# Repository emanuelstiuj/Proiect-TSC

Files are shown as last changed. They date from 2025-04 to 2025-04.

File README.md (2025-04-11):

# OpenBook - E-Reader Project  
**Developed by Emanuel-Stefan Stiuj - TSC 2025**

The OpenBook is an innovative, open-source e-reader designed for low power consumption, expandability, and ease of use. Built around the ESP32-C6-WROOM-1-N8 microcontroller, this project integrates an e-paper display, environmental sensing, real-time clock functionality, and robust storage options into a portable, battery-powered device. This README provides a detailed breakdown of the hardware design, functionality, and implementation, ensuring all critical aspects are covered.

---

board

## Project Overview

OpenBook is a fully functional e-reader that leverages modern hardware to deliver a seamless reading experience. Key features include:
- A 7.5-inch e-paper display for crisp, low-power text rendering.
- Wi-Fi 6 and Bluetooth 5 connectivity via the ESP32-C6 for wireless content updates.
- SD card and external flash storage for e-books and logs.
- Environmental monitoring with the BME688 sensor (temperature, humidity, pressure, air quality).
- Precise timekeeping with the DS3231 RTC module.
- USB-C for power, charging, and data transfer, with a Li-Po battery for portability.
- Expandability through a Qwiic I²C connector.

The design prioritizes energy efficiency, modularity, and user interaction via three tactile buttons, making it ideal for avid readers and hardware enthusiasts alike.

---

## Hardware Architecture

The OpenBook hardware architecture integrates several key components powered through a USB-C input and a Li-Po battery. The system uses a battery charger (MCP73831) to manage the 2500mAh Li-Po battery, which supplies power to an LDO regulator outputting 3.3V. This voltage powers the ESP32-C6-WROOM-1-N8 microcontroller, a 7.5-inch e-paper display, an SD card module, a 64MB NOR Flash, a DS3231 RTC, a BME688 sensor, and a MAX17048 fuel gauge. The ESP32 connects to the display, SD card, and flash via SPI, to the RTC, sensor, and fuel gauge via I²C, and to three tactile buttons via GPIO. The USB-C also provides data connectivity, and a Qwiic connector enables I²C expansion.

---

## Hardware Components and Functionality

### 1. Main Microcontroller: ESP32-C6-WROOM-1-N8
- **Processor**: 32-bit RISC-V, up to 160 MHz.
- **Memory**: 512 KB SRAM + 64 MB external NOR Flash (W25Q512JVEIQ).
- **Connectivity**: Wi-Fi 6 (2.4 GHz), Bluetooth 5 LE, USB 2.0.
- **Interfaces**: SPI, I²C, UART, GPIO.
- **Power**: 3.3V via LDO; supports deep sleep for minimal power use (<10 µA).
- **Why Chosen?**: Offers robust wireless capabilities, ample GPIO, and low-power modes, perfect for an e-reader with connectivity needs.

### 2. E-Paper Display
- **Type**: 7.5-inch Waveshare e-ink display (800x480 resolution).
- **Interface**: 4-wire SPI (MOSI, SCK, CS, DC) + control signals (RST, BUSY).
- **Pins**:
  - `EPD_CS` → `IO10`
  - `EPD_DC` → `IO5`
  - `EPD_RST` → `IO23`
  - `EPD_BUSY` → `IO3`
  - Shared SPI: `MOSI` (`IO7`), `SCK` (`IO6`).
- **Power**: 3.3V, ~20-50 mA during refresh, near-zero in static mode.
- **Why Chosen?**: E-paper’s ultra-low static power consumption makes it ideal for prolonged reading without draining the battery.

### 3. Storage
- **SD Card Module**:
  - **Interface**: SPI.
  - **Pins**: `SS_SD` → `IO4`, `MOSI` → `IO7`, `MISO` → `IO2`, `SCK` → `IO6`.
  - **Purpose**: External storage for e-books and firmware updates.
- **External Flash (W25Q512JVEIQ)**:
  - **Interface**: SPI (Quad I/O).
  - **Pins**: `FLASH_CS` → `IO11`, shared `MOSI`, `MISO`, `SCK`.
  - **Capacity**: 64 MB for firmware and content.
- **Power**: Both operate at 3.3V, with ~10-100 mA during active use.

### 4. Real-Time Clock (RTC): DS3231SN
- **Interface**: I²C.
- **Pins**: `SDA` → `IO21`, `SCL` → `IO22`, `INT_RTC` → `IO8`, `32KHZ` → `IO1`, `RTC_RST` → `IO18`.
- **Power**: 3.3V, <1 µA with backup (super-capacitor or coin cell).
- **Why Chosen?**: Provides accurate timekeeping, critical for timestamped logs or scheduled tasks, even when powered off.

### 5. Environmental Sensor: BME688
- **Measurements**: Temperature, humidity, pressure, VOC/eCO2.
- **Interface**: I²C (shared bus with RTC and Fuel Gauge).
- **Pins**: `SDA` → `IO21`, `SCL` → `IO22`.
- **Power**: 3.3V, ~0.8-3.6 mA active, <1 µA in sleep.
- **Why Chosen?**: Enhances user experience by monitoring reading conditions.

### 6. Power Management
- **Battery**: 2500 mAh Li-Po (3.7V nominal).
- **Charger**: MCP73831, charges via USB-C at up to 1A.
- **Fuel Gauge**: MAX17048, I²C (`SDA`/`SCL`), monitors battery level (~50 µA).
- **LDO Regulator**: XC6220A331MR-G, steps 5V down to 3.3V for all components.
- **USB-C**: Power input (5V) and data (USB_D+ → `IO13`, USB_D- → `IO12`).
- **Protection**: Reverse polarity diodes, ESD protection (USBLC6-2SC6Y).

---

## Communication Interfaces

| Interface | Components | ESP32-C6 Pins | Notes |
|---|---|---|---|
| SPI | E-Paper, SD Card, Flash| `MOSI` (`IO7`), `MISO` (`IO2`), `SCK` (`IO6`) | Shared bus with individual CS pins. |
| I²C | RTC, BME688, Fuel Gauge| `SDA` (`IO21`), `SCL` (`IO22`) | 400 kHz bus, pull-ups included. |
| UART | Debugging | `TXD0`, `RXD0` (test pads) | Optional, for development.  |
| GPIO | Buttons, Status | `IO0`-`IO23` | Flexible assignments. |
| USB | Power/Data | `USB_D+` (`IO13`), `USB_D-` (`IO12`) | USB 2.0 full-speed. |

---

## Power Consumption

| Component | Typical Current (mA) | Notes |
|---|---|---|
| ESP32-C6 (Idle) | ~10 | <10 µA in deep sleep. |
| ESP32-C6 (Wi-Fi) | 80-160 | Peak during wireless activity. |
| E-Paper (Refresh) | 20-50 | Near-zero when static. |
| SD Card | 30-100 | Active during read/write. |
| Flash (NOR) | 10-20 | Intermittent use. |
| BME688 | ~0.8-3.6 | <1 µA in sleep. |
| DS3231 RTC | ~0.2-3.5 | <1 µA with backup. |
| MAX17048 | ~0.05 | Continuous monitoring. |
| **Total (Typical)** | **150-250 mA** | Varies with usage; ~50 µA in sleep. |

**Battery Life**: With a 2500 mAh battery, OpenBook can last weeks in typical use (mostly static display) or hours during heavy Wi-Fi and refresh activity.

---

| **Component Name** | **Component Type** | **Link** |
|---|---|---|
| MicroSD_112ATA | microSD | [Attend SnapEDA](https://www.snapeda.com/parts/112A-TAAR-R03/Attend/view-part/) |
| LED_ADAFRUIT0603 | LED | [Kingbright SnapEDA](https://www.snapeda.com/parts/KP-1608SURCK/Kingbright/view-part/?ref=search&t=LED%200603) |
| CAP_CPH3225 | C | [Seiko SnapEDA](https://www.snapeda.com/parts/CPH3225A/Seiko/view-part/) |
| VREG_XC6220A | Voltage Regulator | [Torex Mouser](https://ro.mouser.com/ProductDetail/Torex-Semiconductor/XC6220A331MR-G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) |
| FUEL_MAX17048 | Cell Fuel Gauge with ModelGauge | [Analog Devices SnapEDA](https://www.snapeda.com/parts/MAX17048G+T10/Analog%20Devices/view-part/) |
| ESP32C6_MODULE | ESP32 | [Espressif SnapEDA](https://www.snapeda.com/parts/ESP32-C6-WROOM-1-N8/Espressif%20Systems/view-part/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) |
| DIODE_MBR0530 | Diode Schottky | [Onsemi SnapEDA](https://www.snapeda.com/parts/MBR0530/Onsemi/view-part/) |
| BME680_SENSOR | Env Sensor | [Bosch SnapEDA](https://www.snapeda.com/parts/BME680/Bosch%20Sensortec/view-part/?ref=search&t=bme680) |
| INDUCTOR_744043 | L | [Wurth Mouser](https://eu.mouser.com/ProductDetail/Wurth-Elektronik/744043680?qs=PGXP4M47uW6VkZq%252BkzjrHA%3D%3D) |
| CONNECTOR_QWIIC | PRT-14417 QWIIC_CONNECTOR | [SparkFun SnapEDA](https://www.snapeda.com/parts/PRT-14417/SparkFun/view-part/) |
| VARSISTOR_ESP | Varsistor (B72520T0350K062) | [TDK Mouser](https://ro.mouser.com/ProductDetail/EPCOS-TDK/B72520T0350K062?qs=dEfas%2FXlABIszF52uu7vrg%3D%3D) |
| RES_RCL0402 | R | [YAGEO ComponentSearch](https://componentsearchengine.com/part-view/R0402%201%25%20100%20K%20(RC0402FR-07100KL)/YAGEO) |
| TVS_PGB1010603 | Ipp Tvs Diode Surface Mount 0603 | [Littelfuse SnapEDA](https://www.snapeda.com/parts/PGB1010603MR/Littelfuse/view-part/) |
| MOSFET_SI1308 | MOSFET Transistor | [Vishay SnapEDA](https://www.snapeda.com/parts/SI1308EDL-T1-GE3/Vishay/view-part/) |
| BUTTON_EVQP7 | Button | [SnapEDA Button](https://www.snapeda.com/search/?q=EVQP7L01P&search-type=parts) |
| USBLC6_TVS | Ipp Tvs Diode Surface Mount | [STMicro SnapEDA](https://www.snapeda.com/parts/USBLC6-2SC6Y/STMicroelectronics/view-part/?ref=dk&t=USBLC6-2SC6Y&con_ref=None) |
| FLASH_W25Q512 | FLASH - NOR Memory | [Winbond SnapEDA](https://www.snapeda.com/parts/W25Q512JVEIQ/Winbond%20Electronics/view-part/?ref=search&t=W25Q512JVEIQ) |
| CAP_ESP32C0402 | C | [YAGEO ComponentSearch](https://componentsearchengine.com/part-view/CC0402MRX5R5BB106/YAGEO) |
| RTC_DS3231 | I²C-Integrated RTC/TCXO/Crystal | [Analog Devices SnapEDA](https://www.snapeda.com/parts/DS3231SN%23/Analog%20Devices/view-part/?ref=search&t=DS3231SN%23) |
| VDET_BD5229 | Voltage Detector | [Rohm SnapEDA](https://www.snapeda.com/parts/BD5229G-TR/Rohm/view-part/?ref=search&t=BD5229G-TR) |
| SCHOTTKY_SD0805 | Diode Schottky | [AVX ComponentSearch](https://componentsearchengine.com/part-view/SD0805S020S1R0/Kyocera%20AVX) |
| MOSFET_DMG2305 | T DMG2305UX-7 | [Diodes ComponentSearch](https://componentsearchengine.com/part-view/DMG2305UX-7/Diodes%20Incorporated) |
| CHARGE_MCP73831 | Tiny Integrated Li-Ion/Li-Poly Charge Mgnt Controller | [Microchip ComponentSearch](https://componentsearchengine.com/part-view/MCP73831T-2ACI%2FOT/Microchip) |
| CONNECTOR_FH34SRJ | FH34SRJ-24S-0.5SH(99) | [Hirose ComponentSearch](https://componentsearchengine.com/part-view/FH34SRJ-24S-0.5SH(99)/Hirose) |
| USB4110_GF | USB4110-GF-A | [GCT SnapEDA](https://www.snapeda.com/parts/USB4110-GF-A./Global%20Connector%20Technology/view-part/) |
| CAP_RCLPOL | C pol | [GrabCAD Tantalum](https://grabcad.com/library/tantalum-smd-capacitor-type-b-3528-1) |
| JUMPER_SJ | Jumper-SolderPasteJumper3way | [GrabCAD Jumper](https://grabcad.com/library/solder-jumpers-1) |

---

## ESP32-C6 Pin Assignments

| Pin | Signal | Function | Reason for Assignment |
|---|---|---|---|
| EN | RESET | System reset | Standard reset pin for ESP32. |
| IO0 | INT_RTC | RTC interrupt | Low-power interrupt capability. |
| IO1 | 32KHZ | 32 kHz RTC clock output | Drives accurate timekeeping. |
| IO2 | MISO | SPI data input (SD/Flash/Display)| Shared SPI bus input. |
| IO3 | EPD_BUSY | E-Paper busy status | Monitors display readiness. |
| IO4 | SS_SD | SD Card chip select | Dedicated CS for SD card. |
| IO5 | EPD_DC | E-Paper data/command | Distinguishes data vs. commands. |
| IO6 | SCK | SPI clock | Shared SPI clock signal. |
| IO7 | MOSI | SPI data output | Shared SPI output for peripherals. |
| IO9 | IO/BOOT | Boot button | Triggers boot mode or power-on. |
| IO10 | EPD_CS | E-Paper chip select | Dedicated CS for display. |
| IO11 | FLASH_CS | Flash chip select | Dedicated CS for NOR Flash. |
| IO12 | USB_D- | USB differential data - | Fixed USB pin. |
| IO13 | USB_D+ | USB differential data + | Fixed USB pin. |
| IO15 | IO/CHANGE | Page change button | User input for navigation. |
| IO18 | RTC_RST | RTC reset | Hardware reset for RTC. |
| IO21 | SDA | I²C data line | Shared I²C bus for sensors/RTC. |
| IO22 | SCL | I²C clock line | Shared I²C clock signal. |
| IO23 | EPD_RST | E-Paper reset | Hardware reset for display. |
| TXD0 | TX | UART transmit (debug) | Test pad for debugging. |
| RXD0 | RX | UART receive (debug) | Test pad for debugging. |

---

## Design Decisions

1. **Power Routing**: Power traces were prioritized and routed manually to ensure stability, followed by autorouting for signal lines.
2. **USB-C Integration**: Modified to avoid DRC errors, supporting both power and data seamlessly.
3. **E-Paper Choice**: Selected for its low power and readability, with a dedicated 3.3V supply controlled via a MOSFET (`EPD_3v3_c`) for efficiency.
4. **Modularity**: Qwiic connector and test pads enhance expandability and debuggability.
5. **ESD Protection**: Added to SPI, USB, and power lines to ensure durability.

---

## Implementation Steps

1. **Schematic Design**: Created in Autodesk Fusion, integrating all components with clear pin mappings.
2. **PCB Layout**: 
   - Defined GND plane and power net classes.
   - Applied custom routing rules for signal integrity.
   - Adjusted enclosure dimensions to fit the PCB.
3. **3D Modeling**: Designed battery and display mounts based on datasheets.
4. **Testing**: Used test pads for UART debugging and verified functionality.

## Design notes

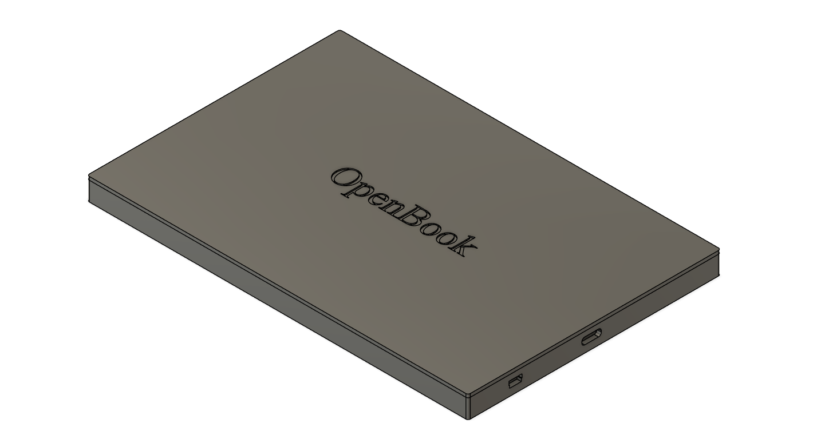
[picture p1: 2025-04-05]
Images/OpenBook_Enclosure.png

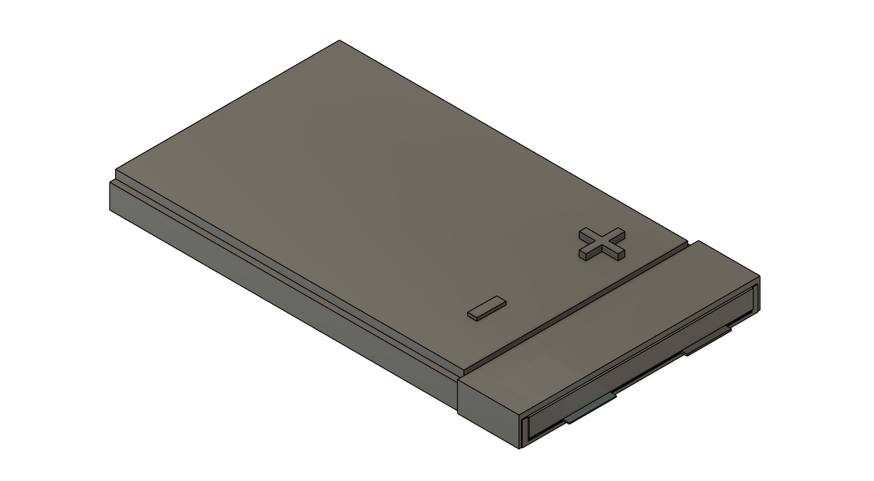
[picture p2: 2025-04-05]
Images/Battery.png

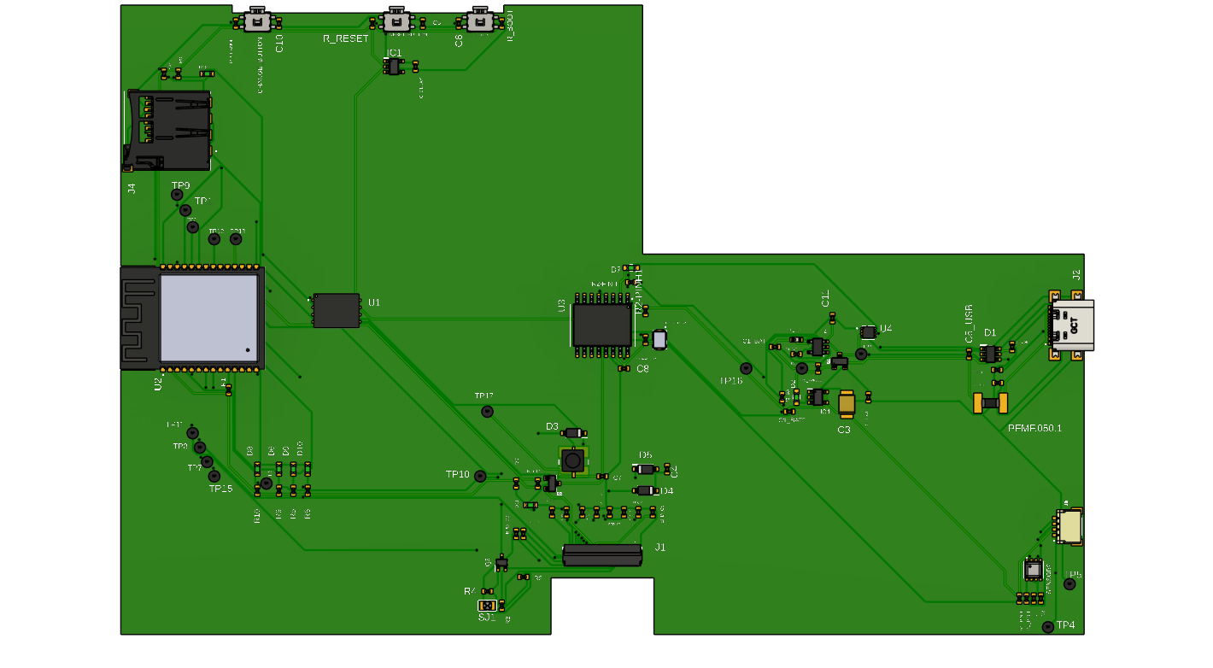
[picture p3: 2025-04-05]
Images/pcb_1.png

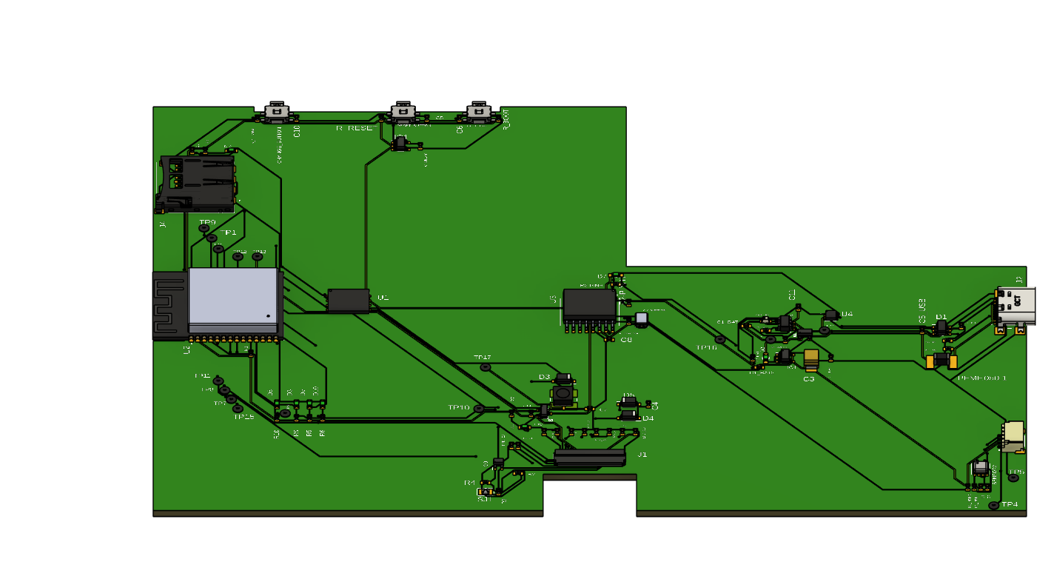
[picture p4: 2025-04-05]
Images/pcb_0.png

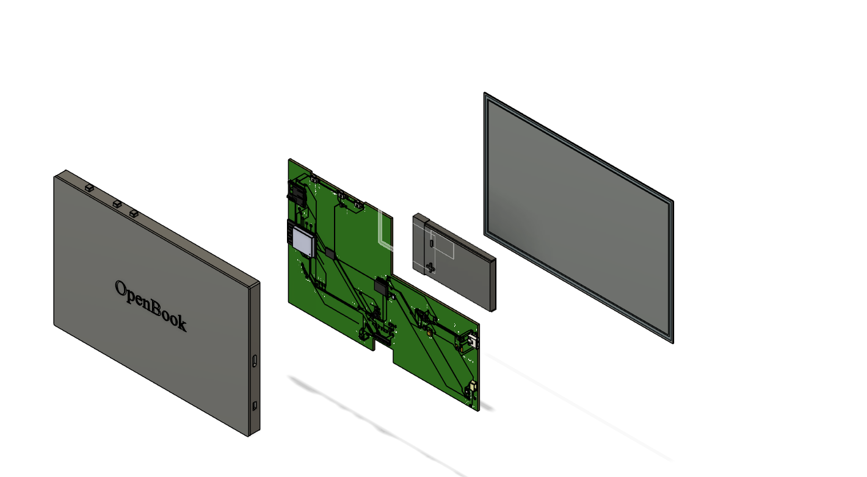
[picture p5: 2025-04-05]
Images/ExplodedView.png

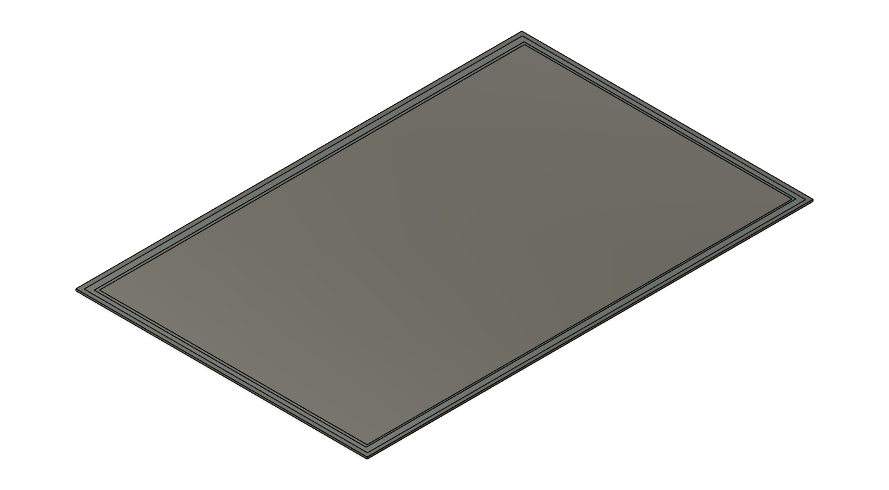
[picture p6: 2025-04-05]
Images/Display.png

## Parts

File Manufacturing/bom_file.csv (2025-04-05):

Qty | Value | Device | Package | Parts | Description | ARROW_PART_NUMBER | ARROW_PRICE-STOCK | AVAILABILITY | CENTROID_NOT_SPECIFIED | CHECK_PRICES | COPYRIGHT | DATASHEET | DESCRIPTION | DIGIKEY_DESCRIPTION | DIGIKEY_PART_NUMBER | HEIGHT | LEAD_FREE | MANUFACTURER_NAME | MANUFACTURER_PART_NUMBER | MF | MFR_NAME | MOUSER_PART_NUMBER | MOUSER_PRICE-STOCK | MOUSER_TESTING_PART_NUMBER | MOUSER_TESTING_PRICE-STOCK | MP | MPN | PACKAGE | POPULARITY | PREFIX | PRICE | PROD_ID | PURCHASE-URL | ROHS | SNAPEDA_LINK | SPICEPREFIX | TEMPERATURE_RANGE_HIGH | TEMPERATURE_RANGE_LOW | TP_SIGNAL_NAME | VALUE
1 |  | ADAFRUIT_LEDCHIP-LED0603 | ADAFRUIT_CHIP-LED0603 | CHG_LED | LED
1 |  | SJSJ_2WAY | SJ | SJ1 | SMD solder JUMPER
1 | 0.1uF/50V | ESP32_WROVER_EAGLE-LTSPICE_C | ESP32_WROVER_EAGLE-LTSPICE_C0402 | EPD_C5 | CAPACITOR, European symbol
1 | 0.47 | ESP32_WROVER_EAGLE-LTSPICE_R | ESP32_WROVER_EAGLE-LTSPICE_R0402 | R3 | RESISTOR, European symbol
1 | 100K | ESP32_WROVER_EAGLE-LTSPICE_R | ESP32_WROVER_EAGLE-LTSPICE_R0402 | R1_PWRUSB | RESISTOR, European symbol
8 | 100nF | ESP32_WROVER_EAGLE-LTSPICE_C | ESP32_WROVER_EAGLE-LTSPICE_C0402 | C1, C2, C4_USB, C6, C8, C9, C10, C_DELAY | CAPACITOR, European symbol
1 | 100uF TANT | RCL_CPOL-EUCT3528 | RCL_CT3528 | C3 | POLARIZED CAPACITOR, European symbol |  |  |  |  |  |  |  |  |  |  |  |  |  |  |  |  |  |  |  |  |  |  |  | 0 |  |  |  |  |  |  | C
16 | 10K | ESP32_WROVER_EAGLE-LTSPICE_R | ESP32_WROVER_EAGLE-LTSPICE_R0402 | R1, R1_PINH, R1_PINH1, R2-PINH, R2-PINH1, R4, R5, R6, R7, R8, R9, R10, R_BOOT, R_CHANGE, R_CL1, R_RESET | RESISTOR, European symbol
1 | 10uF | ESP32_WROVER_EAGLE-LTSPICE_C | ESP32_WROVER_EAGLE-LTSPICE_C0402 | C7 | CAPACITOR, European symbol
1 | 112A-TAAR-R03_ATTEND | 112A-TAAR-R03_ATTEND | 112ATAARR03ATTEND | J4 | Micro SD Card Socket, Push-Push Type, Top Mount, SMT, H=1.83mm, 10u |  |  |  |  |  |  |  | Micro SD Card Socket | Push-Push Type | Top Mount | SMT | H=1.83mm | 10u |  |  | 1.9mm |  | ATTEND | 112A-TAAR-R03 ATTEND
1 | 15 | ESP32_WROVER_EAGLE-LTSPICE_R | ESP32_WROVER_EAGLE-LTSPICE_R0402 | R_CAPACITOR | RESISTOR, European symbol
1 | 1uF | ESP32_WROVER_EAGLE-LTSPICE_C | ESP32_WROVER_EAGLE-LTSPICE_C0402 | C5 | CAPACITOR, European symbol
9 | 1uF/50V | ESP32_WROVER_EAGLE-LTSPICE_C | ESP32_WROVER_EAGLE-LTSPICE_C0402 | EPD_C1\, EPD_C2, EPD_C6, EPD_C7, EPD_C8, EPD_C9, EPD_C10, EPD_C11, EPD_C12 | CAPACITOR, European symbol
1 | 2.2 | ESP32_WROVER_EAGLE-LTSPICE_R | ESP32_WROVER_EAGLE-LTSPICE_R0402 | R2 | RESISTOR, European symbol
1 | 200 | ESP32_WROVER_EAGLE-LTSPICE_R | ESP32_WROVER_EAGLE-LTSPICE_R0402 | R1_BAT | RESISTOR, European symbol
2 | 20V/4.2A/52mO/1.4W | ESP32_WROVER_SPARKFUN-DISCRETESEMI_MOSFET_PCH-DMG2305UX-7 | ESP32_WROVER_SPARKFUN-DISCRETESEMI_SOT23-3 | Q1, Q2 | P-channel MOSFETs |  |  |  |  |  |  |  |  |  |  |  |  |  |  |  |  |  |  |  |  |  |  |  |  |  |  | TRAN-14388 |  |  |  |  |  |  |  | 20V/4.2A/52mO/1.4W
1 | 2K | ESP32_WROVER_EAGLE-LTSPICE_R | ESP32_WROVER_EAGLE-LTSPICE_R0402 | R2_BAT | RESISTOR, European symbol
5 | 4.7uF | ESP32_WROVER_EAGLE-LTSPICE_C | ESP32_WROVER_EAGLE-LTSPICE_C0402 | C1_BAT, C1_BAT1, C1_BAT2, C5_USB, C11 | CAPACITOR, European symbol
1 | 4.7uF/25V | ESP32_WROVER_EAGLE-LTSPICE_C | ESP32_WROVER_EAGLE-LTSPICE_C0402 | C4 | CAPACITOR, European symbol
2 | 5k1 | ESP32_WROVER_EAGLE-LTSPICE_R | ESP32_WROVER_EAGLE-LTSPICE_R0402 | R2-USB, R2-USB1 | RESISTOR, European symbol
1 | 68uH | 744043680IND_4828-WE-TPC_WRE | IND_4828-WE-TPC_WRE | L1 |  |  |  |  |  |  | Copyright (C) 2024 Ultra Librarian. All rights reserved. |  |  |  |  |  |  |  | 744043680 |  | Wurth Electronics
1 | BD5229G-TR | BD5229G-TR | SOT95P280X125-5N | IC1 | Voltage Detector with Adjustable Delay Time: CMOS processes are utilized to develop high precision, low current consumption CMOS reset ICs that allow arbitrary setting of the delay time. The extensive lineup includes both Nch Open Drain and CMOS output types in a wide range of detection voltages (from 2.3V to 6.0V, in 0.1V steps), enabling selection of the ideal solution based on customer requirements. In addition, the entire series is of course both lead-free and RoHS-compliant. |  |  |  |  |  |  |  | Voltage Detector with Adjustable Delay Time: CMOS processes are utilized to develop high precision | low current consumption CMOS reset ICs that allow arbitrary setting of the delay time. The extensive lineup includes both Nch Open Drain and CMOS output types in a wide range of detection voltages (from 2.3V to 6.0V | in 0.1V steps) | enabling selection of the ideal solution based on customer requirements. In addition | the entire series is of course both lead-free and RoHS-compliant. |  |  | 1.25mm |  | ROHM Semiconductor | BD5229G-TR |  |  | 755-BD5229G-TR | https://www.mouser.co.uk/ProductDetail/ROHM-Semiconductor/BD5229G-TR?qs=4kLU8WoGk0vvnhrrYwdszw%3D%3D
1 | BME688 | ESP32_WROVER_BME680_BME680 | ESP32_WROVER_BME680_PSON80P300X300X100-8N | SENSOR2 | Integrated Environmental Unit |  |  | Unavailable |  |  |  |  | Integrated Environmental Unit |  |  |  |  |  |  | Bosch Sensortec |  |  |  |  |  | BME680 |  | LGA-8 Bosch Tools |  |  | None
1 | BOOT_BUTTON | BUTTON_CUSYOMV1 | MYBUTTON | BOOT_BUTTON
1 | CHANGE_BUTTON | BUTTON_CUSYOMV1 | MYBUTTON | CHANGE_BUTTON
1 | CPH3225ACPH | CPH3225ACPH | CAPCP3225X100N | C10_SUPERCAP | Cap 0.011F 3.3V 1210 Flat Check availability
1 | DS3231SN# | DS3231SN# | SOIC127P1032X265-16N | U3 | Real Time Clock Serial 16-Pin SOIC W T/R Check availability |  |  | In Stock |  | https://www.snapeda.com/parts/DS3231SN%23/Analog+Devices/view-part/?ref=eda |  |  | Extremely Accurate I²C-Integrated RTC/TCXO/Crystal |  |  |  |  |  |  | Analog Devices |  |  |  |  |  | DS3231SN# |  | SOIC-16 Maxim |  |  | None |  | https://www.snapeda.com/api/url_track_click_mouser/?unipart_id=99048&manufacturer=Analog Devices&part_name=DS3231SN#&search_term=None |  | https://www.snapeda.com/parts/DS3231SN%23/Analog+Devices/view-part/?ref=snap
1 | ESP32-C6-WROOM-1-N8 | ESP32-C6-WROOM-1-N8 | XCVR_ESP32-C6-WROOM-1-N8 | U2 | Check availability |  |  | In Stock |  | https://www.snapeda.com/parts/ESP32-C6-WROOM-1-N8/Espressif+Systems/view-part/?ref=eda |  |  | Multiprotocol Modules ESP32-C6 module | Wi-Fi 6 in 2.4 GHz band | Bluetooth 5 | Zigbee 3.0 and Thread. ESP34-WROOM Compatible - ENGINEERING SAMPLE |  |  |  |  |  |  | Espressif Systems |  |  |  |  |  | ESP32-C6-WROOM-1-N8 |  | None |  |  | None |  |  |  | https://www.snapeda.com/parts/ESP32-C6-WROOM-1-N8/Espressif+Systems/view-part/?ref=snap
1 | ESP32C6_VARISTOR | ESP32C6_VARISTOR | ESP32C6_VARISTOR_CT/CN1812 | PFMF.050.1 | VARISTOR
1 | ESP32_WROVER_AVX---SD0805S020S1R0_AVX_SD0805S020S1R0_0_0AVX_SD0805S020S1R0_0_0 | ESP32_WROVER_AVX---SD0805S020S1R0_AVX_SD0805S020S1R0_0_0AVX_SD0805S020S1R0_0_0 | ESP32_WROVER_AVX---SD0805S020S1R0_AVX_SD0805S020S1R0_0 | D7 | Schottky Barrier Rectifier Diode |  |  |  | No |  |  | http://datasheets.avx.com/schottky.pdf |  | DIODE SCHOTTKY 20V 1A 0805 | 478-7800-1-ND |  | yes |  |  | AVX |  | 581-SD0805S020S1R0 |  |  |  |  |  | 0805 (2012 metric) |  | D |  |  |  | yes |  |  | +125°C | -55°C
1 | FH34SRJ-24S-0.5SH_99_FH34 | FH34SRJ-24S-0.5SH_99_FH34 | FH34SRJ24S05SH99 | J1 | (0.50mm) Surface Mount, Right Angle
1 | MAX17048G+T10 | MAX17048G+T10 | SON50P200X200X80-9N | U4 | Check availability |  |  | In Stock |  | https://www.snapeda.com/parts/MAX17048G+T10/Analog+Devices/view-part/?ref=eda |  |  | 3µA 1-Cell/2-Cell Fuel Gauge with ModelGauge |  |  |  |  |  |  | Analog Devices |  |  |  |  |  | MAX17048G+T10 |  | TDFN-8 Maxim |  |  | None |  | https://www.snapeda.com/api/url_track_click_mouser/?unipart_id=329239&manufacturer=Analog Devices&part_name=MAX17048G+T10&search_term=None |  | https://www.snapeda.com/parts/MAX17048G+T10/Analog+Devices/view-part/?ref=snap
3 | MBR0530 | MBR0530 | SOD3716X135N | D3, D4, D5 | ON SEMICONDUCTOR - MBR0530 - DIODE, SCHOTTKY, 0.5A, 30V, SOD-123 |  |  | In Stock |  | https://www.snapeda.com/parts/MBR0530/Onsemi/view-part/?ref=eda |  |  | Diode Schottky 30 V 500mA Surface Mount SOD-123 |  |  |  |  |  |  | ON Semiconductor |  |  |  |  |  | MBR0530 |  | SOD-123-2 ON Semiconductor |  |  | None |  | https://www.snapeda.com/api/url_track_click_mouser/?unipart_id=179458&manufacturer=ON Semiconductor&part_name=MBR0530&search_term=None |  | https://www.snapeda.com/parts/MBR0530/Onsemi/view-part/?ref=snap
1 | MCP73831 | ESP32_WROVER_SPARKFUN-IC-POWER_MCP73831 | ESP32_WROVER_SPARKFUN-IC-POWER_SOT23-5 | U5 | MCP73831T Li-Ion, Li-Pol Controller |  |  |  |  |  |  |  |  |  |  |  |  |  |  |  |  |  |  |  |  |  |  |  |  |  |  | IC-09995
6 | PGB1010603MR | PGB1010603MR | DIOC1608X36N | D6, D8, D9, D10, D11, D12 | Check availability |  |  | In Stock |  | https://www.snapeda.com/parts/PGB1010603MR/Littelfuse/view-part/?ref=eda |  |  | 150V (Typ) Clamp - Ipp Tvs Diode Surface Mount 0603 (1608 Metric) |  |  |  |  |  |  | Littelfuse Inc. |  |  |  |  |  | PGB1010603MR |  | 0603 Littelfuse Inc. |  |  | None |  | https://www.snapeda.com/api/url_track_click_mouser/?unipart_id=5659453&manufacturer=Littelfuse Inc.&part_name=PGB1010603MR&search_term=None |  | https://www.snapeda.com/parts/PGB1010603MR/Littelfuse/view-part/?ref=snap
1 | QWIIC_RIGHT_ANGLE | QWIIC_CONNECTORJS-1MM | JST04_1MM_RA | J3 | SparkFun I2C Standard Qwiic Connector |  |  |  |  |  |  |  |  |  |  |  |  |  |  |  |  |  |  |  |  |  |  |  |  |  |  | CONN-13694 |  |  |  |  |  |  |  | QWIIC_RIGHT_ANGLE
1 | RESET_BUTTON | BUTTON_CUSYOMV1 | MYBUTTON | RESET_BUTTON
1 | SAMACSYS_PARTS_USB4110-GF-A | SAMACSYS_PARTS_USB4110-GF-A | SAMACSYS_PARTS_USB4110GFA | J2 | CONN USB 2.0 TYPE-C R/A SMT |  |  |  |  |  |  |  | CONN USB 2.0 TYPE-C R/A SMT |  |  | 3.26mm |  | GCT (GLOBAL CONNECTOR TECHNOLOGY) | USB4110-GF-A |  |  | 640-USB4110-GF-A | https://www.mouser.co.uk/ProductDetail/GCT/USB4110-GF-A?qs=KUoIvG%2F9IlYiZvIXQjyJeA%3D%3D
1 | SD0805S020S1R0 | ESP32_WROVER_AVX---SD0805S020S1R0_AVX_SD0805S020S1R0_0_0AVX_SD0805S020S1R0_0_0 | ESP32_WROVER_AVX---SD0805S020S1R0_AVX_SD0805S020S1R0_0 | D2 | Schottky Barrier Rectifier Diode |  |  |  | No |  |  | http://datasheets.avx.com/schottky.pdf |  | DIODE SCHOTTKY 20V 1A 0805 | 478-7800-1-ND |  | yes |  |  | AVX |  | 581-SD0805S020S1R0 |  |  |  |  |  | 0805 (2012 metric) |  | D |  |  |  | yes |  |  | +125°C | -55°C
1 | SI1308EDL-T1-GE3 | SI1308EDL-T1-GE3 | SOT65P210X110-3N | Q3 | MOSFET N-Ch 30V 1.5A TrenchFET SC70 Vishay Si1308EDL-T1-GE3 N-channel MOSFET Transistor, 1.5 A, 30 V, 3-Pin SC-70 |  |  | In Stock |  | https://www.snapeda.com/parts/SI1308EDL-T1-GE3/Vishay+Siliconix/view-part/?ref=eda |  |  | Si1308EDL-T1-GE3 N-channel MOSFET Transistor | 1.5 A | 30 V | 3-Pin SC-70 | Siliconix / Vishay SI1308EDL-T1-GE3 |  |  |  |  |  |  | Vishay Siliconix |  |  |  |  |  | SI1308EDL-T1-GE3 |  | SOT-323 Vishay Semiconductor |  |  | None |  | https://www.snapeda.com/api/url_track_click_mouser/?unipart_id=274603&manufacturer=Vishay Siliconix&part_name=SI1308EDL-T1-GE3&search_term=None |  | https://www.snapeda.com/parts/SI1308EDL-T1-GE3/Vishay+Siliconix/view-part/?ref=snap
17 | TPTP20R | TPTP20R | TP20R | TP1, TP2, TP3, TP4, TP5, TP6, TP7, TP8, TP9, TP10, TP11, TP12, TP13, TP14, TP15, TP16, TP17 | Test pad |  |  |  |  |  |  |  |  |  |  |  |  |  |  |  |  |  |  |  |  |  |  |  | 2
1 | USBLC6-2SC6Y | USBLC6-2SC6Y | SOT95P280X145-6N | D1 | Low Cap. ESD Protection Auto SOT-23-6 STMicroelectronics USBLC6-2SC6Y, Dual Uni-Directional TVS Diode Array, 6-Pin SOT-23 |  |  | In Stock |  | https://www.snapeda.com/parts/USBLC6-2SC6Y/STMicroelectronics/view-part/?ref=eda |  |  | 17V Clamp 5A (8/20µs) Ipp Tvs Diode Surface Mount SOT-23-6 |  |  |  |  |  |  | STMicroelectronics |  |  |  |  |  | USBLC6-2SC6Y |  | SOT-23-6 STMicroelectronics |  |  | None |  |  |  | https://www.snapeda.com/parts/USBLC6-2SC6Y/STMicroelectronics/view-part/?ref=snap
1 | W25Q512JVEIQ | W25Q512JVEIQ | SON127P600X800X80-9N | U1 | Check availability |  |  | In Stock |  | https://www.snapeda.com/parts/W25Q512JVEIQ/Winbond+Electronics/view-part/?ref=eda |  |  | FLASH - NOR Memory IC 512Mb (64M x 8) SPI - Quad I/O 133 MHz 8-WSON (8x6) |  |  |  |  |  |  | Winbond Electronics |  |  |  |  |  | W25Q512JVEIQ |  | Package |  |  | None |  |  |  | https://www.snapeda.com/parts/W25Q512JVEIQ/Winbond+Electronics/view-part/?ref=snap
1 | XC6220A331MR-G | XC6220A331MR-G | SOT95P280X120-5N | IC4 | LDO Voltage Regulators |  |  |  |  |  |  |  | LDO Voltage Regulators |  |  | 1.2mm |  | Torex | XC6220A331MR-G |  |  | 865-XC6220A331MR-G | https://www.mouser.co.uk/ProductDetail/Torex-Semiconductor/XC6220A331MR-G?qs=AsjdqWjXhJ8ZSWznL1J0gg%3D%3D

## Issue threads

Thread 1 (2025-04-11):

Text size for component names on PCB is too small

teodora-voicu, 2025-04-11:
**Description:**
The reference designators (e.g., R1, C3) on the PCB are too small to read comfortably.

**Impact:**
Hard to identify components during assembly, testing, or debugging.

**Suggestion:**
Click right on the label -> _properties_

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

Increase the size

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

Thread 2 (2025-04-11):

Missing README file

teodora-voicu, 2025-04-11:
**Description**
The repository currently does not include a README.md file.

**Impact**
It’s hard to understand the purpose, setup steps, and usage of the project without any documentation.

**Suggestion**
Add a README.md file with at least the minimum required structure.
For reference, the expected contents are described here: [https://ocw.cs.pub.ro/courses/tsc/proiect2025](url)

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

Closed 2025-04-13.

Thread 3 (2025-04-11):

PCB thickness should be 1 mm instead of 1.6 mm

teodora-voicu, 2025-04-11:
**Description**
The PCB thickness is currently set to 1.6 mm, although the project requirements specify a thickness of 1.0 mm.

**Impact**
Using a thicker PCB could lead to fitting issues with the enclosure or violate mechanical tolerances in the final assembly.

**Suggestion**

_Rules_ -> _Preferences_ -> _Layer Stack_

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

Change thickness to 1.0 mm

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

Closed 2025-04-13.

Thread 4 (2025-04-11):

Inductor footprint is too small

teodora-voicu, 2025-04-11:
**Description**
The footprint defined for the inductor appears to be smaller than the actual dimensions required by the physical component.

**Impact**
This could lead to soldering issues, mechanical stress, or the component not fitting properly on the PCB during assembly.

**Suggestion**
Update the footprint to match the recommended land pattern from the component’s datasheet.

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

Closed 2025-04-13.

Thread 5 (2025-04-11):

Test pads should display actual signal names, not generic labels

teodora-voicu, 2025-04-11:
**Description**
Currently, test pads are labeled with generic identifiers such as TP1, TP2, etc. These should be clearly labeled on the silkscreen with the actual signal names they correspond to (e.g., MISO, MOSI, RX, GND) for easier identification and debugging.

**Impact**
Generic labels make debugging and testing more difficult, especially for those unfamiliar with the board. Clear signal names improve usability, facilitate servicing, and minimize the risk of probing mistakes.

**Suggestion**
Right-click on each test pad, go to Properties, and update the name to reflect the corresponding signal.

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

Closed 2025-04-13.

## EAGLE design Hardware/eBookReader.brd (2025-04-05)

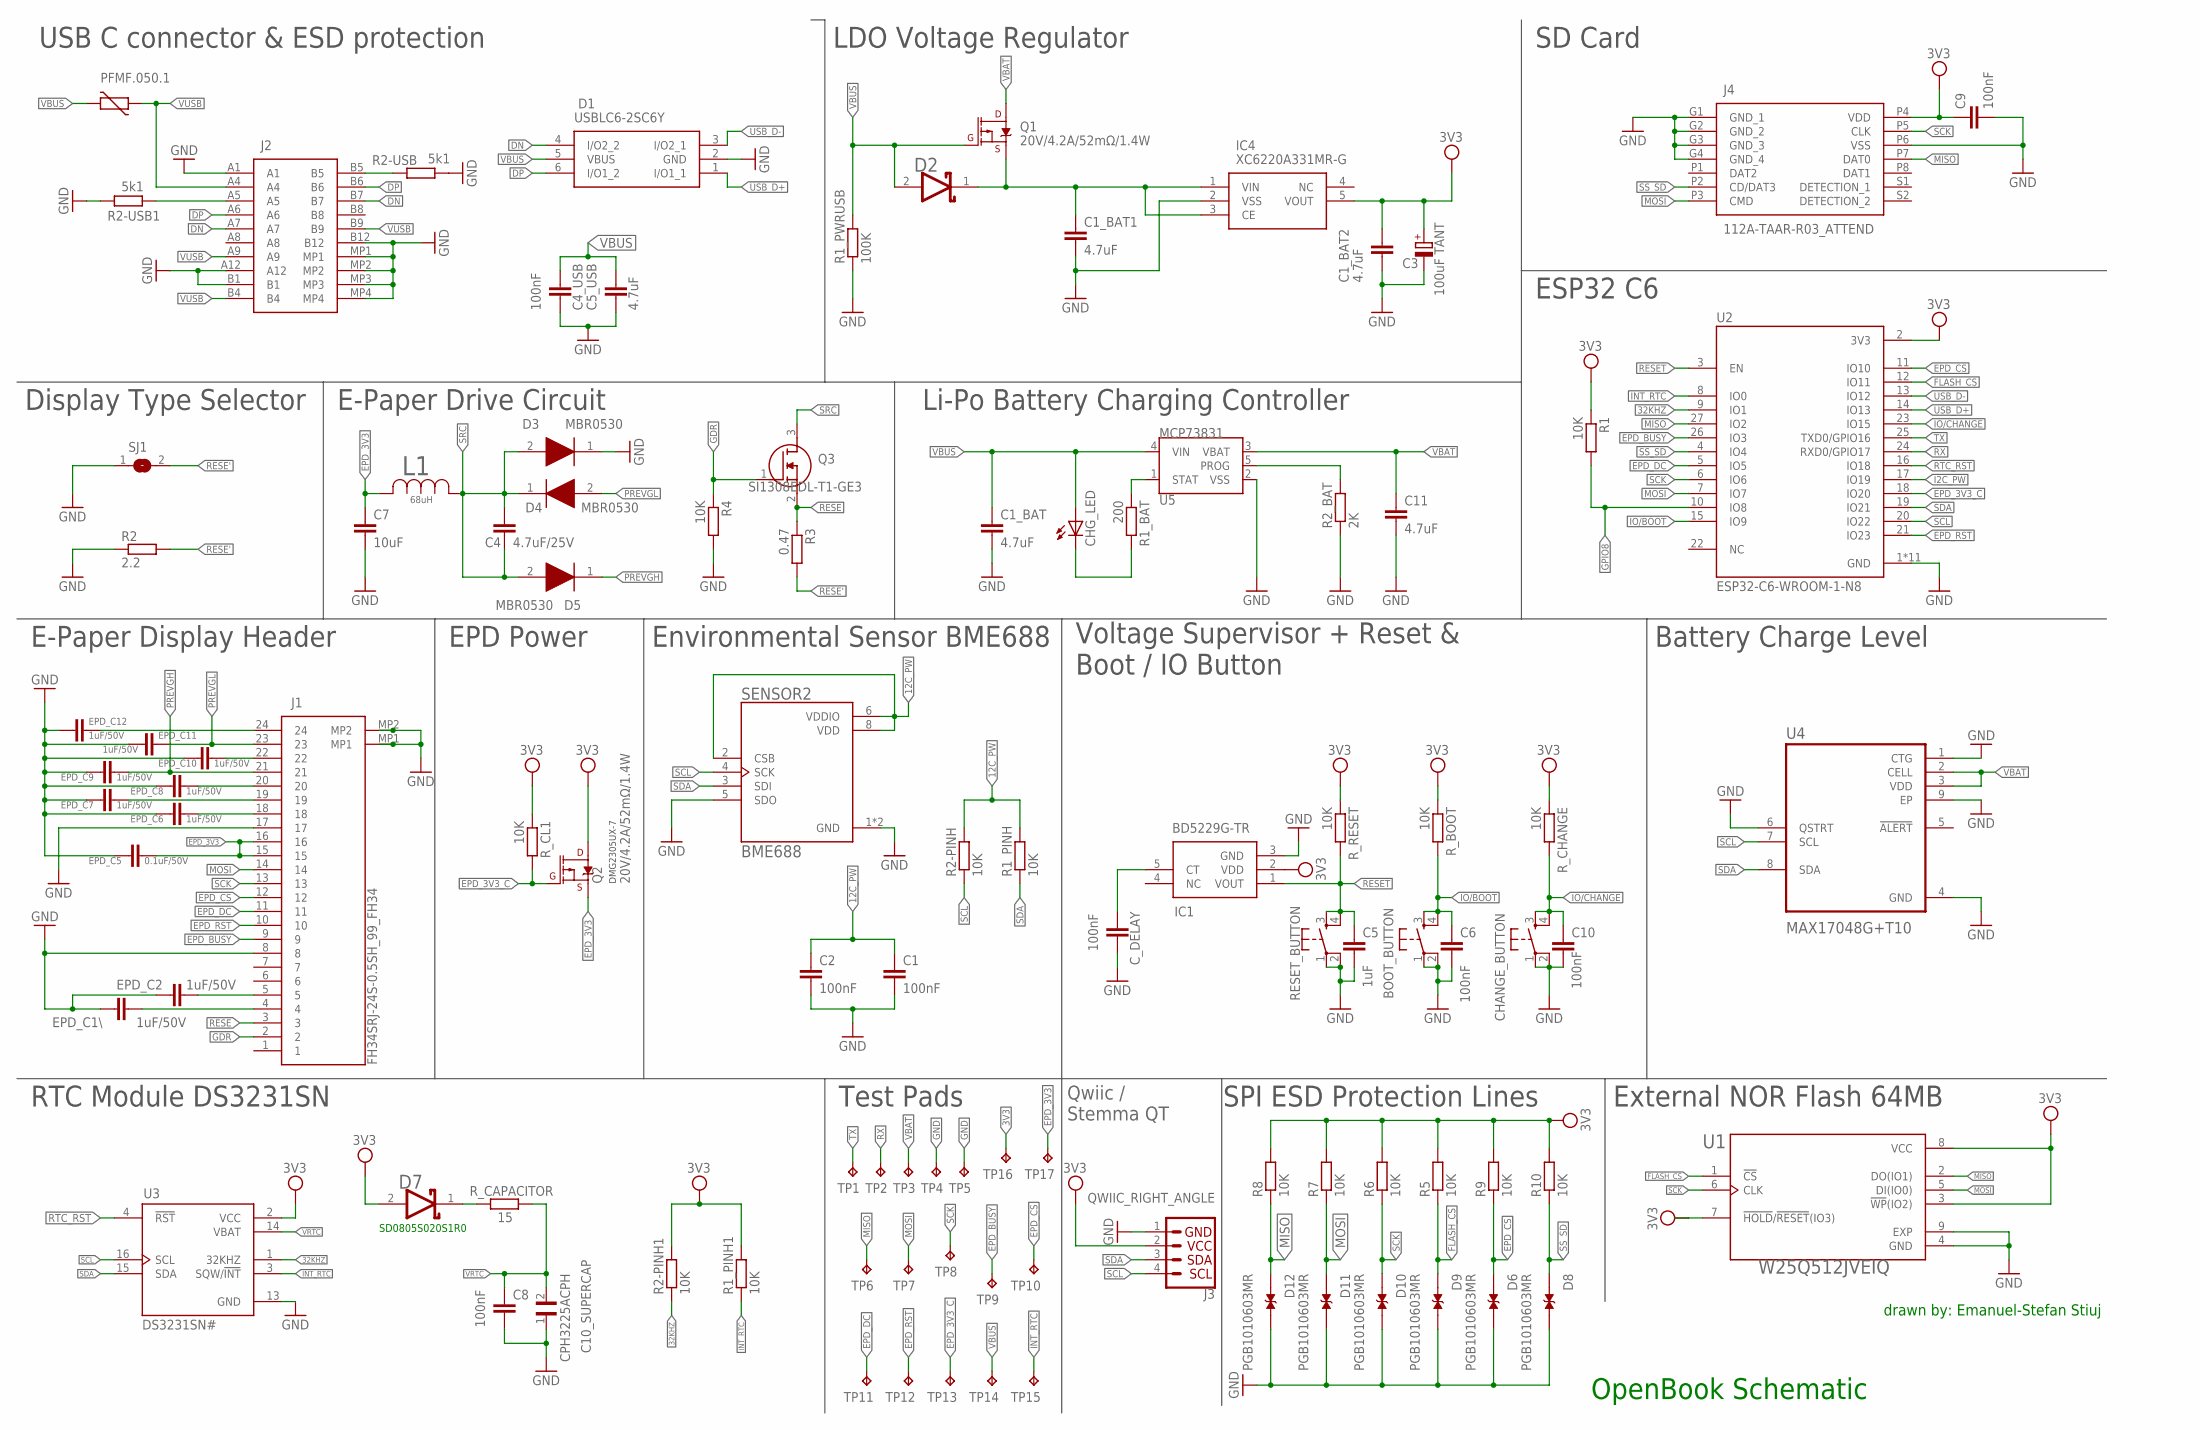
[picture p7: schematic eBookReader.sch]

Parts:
BOOT_BUTTON: BOOT_BUTTON; MYBUTTON
C1, C2, C4_USB, C6, C8, C9, C10: 100nF; ESP32_WROVER_EAGLE-LTSPICE_C0402
C1_BAT, C1_BAT1, C1_BAT2, C5_USB, C11: 4.7uF; ESP32_WROVER_EAGLE-LTSPICE_C0402
C3: 100uF TANT; RCL_CT3528
C4: 4.7uF/25V; ESP32_WROVER_EAGLE-LTSPICE_C0402
C5: 1uF; ESP32_WROVER_EAGLE-LTSPICE_C0402
C7: 10uF; ESP32_WROVER_EAGLE-LTSPICE_C0402
C10_SUPERCAP: CPH3225ACPH; CAPCP3225X100N
CHANGE_BUTTON: CHANGE_BUTTON; MYBUTTON
CHG_LED: ADAFRUIT_LEDCHIP-LED0603; ADAFRUIT_CHIP-LED0603
C_DELAY: 100nF; ESP32_WROVER_EAGLE-LTSPICE_C0402
D1: USBLC6-2SC6Y; SOT95P280X145-6N
D2: SD0805S020S1R0; ESP32_WROVER_AVX---SD0805S020S1R0_AVX_SD0805S020S1R0_0
D3, D4, D5: MBR0530; SOD3716X135N
D6, D8, D9, D10, D11, D12: PGB1010603MR; DIOC1608X36N
D7: ESP32_WROVER_AVX---SD0805S020S1R0_AVX_SD0805S020S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; ESP32_WROVER_AVX---SD0805S020S1R0_AVX_SD0805S020S1R0_0
EPD_C1\, EPD_C2, EPD_C6, EPD_C7, EPD_C8, EPD_C9, EPD_C10, EPD_C11, EPD_C12: 1uF/50V; ESP32_WROVER_EAGLE-LTSPICE_C0402
EPD_C5: 0.1uF/50V; ESP32_WROVER_EAGLE-LTSPICE_C0402
IC1: BD5229G-TR; SOT95P280X125-5N
IC4: XC6220A331MR-G; SOT95P280X120-5N
J1: FH34SRJ-24S-0.5SH_99_FH34; FH34SRJ24S05SH99
J2: SAMACSYS_PARTS_USB4110-GF-A; SAMACSYS_PARTS_USB4110GFA
J3: QWIIC_RIGHT_ANGLE; JST04_1MM_RA
J4: 112A-TAAR-R03_ATTEND; 112ATAARR03ATTEND
L1: 68uH; IND_4828-WE-TPC_WRE
PFMF.050.1: ESP32C6_VARISTOR; ESP32C6_VARISTOR_CT/CN1812
Q1, Q2: 20V/4.2A/52mΩ/1.4W; ESP32_WROVER_SPARKFUN-DISCRETESEMI_SOT23-3
Q3: SI1308EDL-T1-GE3; SOT65P210X110-3N
R1, R1_PINH, R1_PINH1, R2-PINH, R2-PINH1, R4, R5, R6, R7, R8, R9, R10: 10K; ESP32_WROVER_EAGLE-LTSPICE_R0402
R1_BAT: 200; ESP32_WROVER_EAGLE-LTSPICE_R0402
R1_PWRUSB: 100K; ESP32_WROVER_EAGLE-LTSPICE_R0402
R2: 2.2; ESP32_WROVER_EAGLE-LTSPICE_R0402
R2-USB, R2-USB1: 5k1; ESP32_WROVER_EAGLE-LTSPICE_R0402
R2_BAT: 2K; ESP32_WROVER_EAGLE-LTSPICE_R0402
R3: 0.47; ESP32_WROVER_EAGLE-LTSPICE_R0402
RESET_BUTTON: RESET_BUTTON; MYBUTTON
R_BOOT: 10K; ESP32_WROVER_EAGLE-LTSPICE_R0402
R_CAPACITOR: 15; ESP32_WROVER_EAGLE-LTSPICE_R0402
R_CHANGE: 10K; ESP32_WROVER_EAGLE-LTSPICE_R0402
R_CL1: 10K; ESP32_WROVER_EAGLE-LTSPICE_R0402
R_RESET: 10K; ESP32_WROVER_EAGLE-LTSPICE_R0402
SENSOR2: BME688; ESP32_WROVER_BME680_PSON80P300X300X100-8N
SJ1: SJSJ_2WAY; SJ
TP1, TP2, TP3, TP4, TP5, TP6, TP7, TP8, TP9, TP10, TP11, TP12, TP13, TP14, TP15, TP16, TP17: TPTP20R; TP20R
U1: W25Q512JVEIQ; SON127P600X800X80-9N
U2: ESP32-C6-WROOM-1-N8; XCVR_ESP32-C6-WROOM-1-N8
U3: DS3231SN#; SOIC127P1032X265-16N
U4: MAX17048G+T10; SON50P200X200X80-9N
U5: MCP73831; ESP32_WROVER_SPARKFUN-IC-POWER_SOT23-5

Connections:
3V3: C1_BAT2.1, C3.+, C9.1, D7.2 (ANODE), IC1.2 (VDD), IC4.4 (NC), IC4.5 (VOUT), J3.2, J4.P4 (VDD), Q2.3 (D), R1.1, R1_PINH1.2, R2-PINH1.2, R5.2, R6.2, R7.2, R8.2, R9.2, R10.2, R_BOOT.1, R_CHANGE.1, R_CL1.1, R_RESET.1, TP16.TP, U1.3 (!WP!(IO2)), U1.7 (!HOLD!/!RESET!(IO3)), U1.8 (VCC), U2.2 (3V3), U3.2 (VCC)
12C_PW: C1.1, C2.1, R1_PINH.2, R2-PINH.2, SENSOR2.2 (CSB), SENSOR2.6 (VDDIO), SENSOR2.8 (VDD)
32KHZ: R2-PINH1.1, U2.9 (IO1), U3.1 (32KHZ)
DN: D1.4 (I/O2_2), J2.A7, J2.B7
DP: D1.6 (I/O1_2), J2.A6, J2.B6
EPD_3V3: C7.1, EPD_C5.1, J1.15, J1.16, L1.2, Q2.2 (S), TP17.TP
EPD_3V3_C: Q2.1 (G), R_CL1.2, TP13.TP, U2.18 (IO20)
EPD_BUSY: J1.9, TP9.TP, U2.26 (IO3)
EPD_CS: D6.1, J1.12, R9.1, TP10.TP, U2.11 (IO10)
EPD_DC: J1.11, TP11.TP, U2.5 (IO5)
EPD_RST: J1.10, TP12.TP, U2.21 (IO23)
FLASH_CS: D9.1, R5.1, U1.1 (!CS), U2.12 (IO11)
GDR: J1.2, Q3.1 (G), R4.1
GND: BOOT_BUTTON.1, BOOT_BUTTON.2, C1.2, C1_BAT.2, C1_BAT1.2, C1_BAT2.2, C2.2, C3.-, C4_USB.2, C5.2, C5_USB.2, C6.2, C7.2, C8.2, C9.2, C10.2, C10_SUPERCAP.1, C11.2, CHANGE_BUTTON.1, CHANGE_BUTTON.2, C_DELAY.2, D1.2 (GND), D3.1 (K), D6.2, D8.2, D9.2, D10.2, D11.2, D12.2, EPD_C1\.2, EPD_C2.2, EPD_C5.2, EPD_C6.2, EPD_C7.2, EPD_C8.2, EPD_C9.2, EPD_C10.2, EPD_C11.2, EPD_C12.2, IC1.3 (GND), IC4.2 (VSS), J1.8, J1.17, J1.MP1, J1.MP2, J2.A1, J2.A12, J2.B1, J2.B12, J2.MP1, J2.MP2, J2.MP3, J2.MP4, J3.1, J4.G1 (GND_1), J4.G2 (GND_2), J4.G3 (GND_3), J4.G4 (GND_4), J4.P6 (VSS), R1_PWRUSB.1, R2.1, R2-USB.2, R2-USB1.1, R2_BAT.1, R4.2, RESET_BUTTON.1, RESET_BUTTON.2, SENSOR2.1 (GND), SENSOR2.5 (SDO), SENSOR2.7 (GND), SJ1.1, TP4.TP, TP5.TP, U1.4 (GND), U1.9 (EXP), U2.1 (GND), U2.28 (GND), U2.29_1 (GND), U2.29_2 (GND), U2.29_3 (GND), U2.29_4 (GND), U2.29_5 (GND), U2.29_6 (GND), U2.29_7 (GND), U2.29_8 (GND), U2.29_9 (GND), U3.13 (GND), U4.1 (CTG), U4.4 (GND), U4.6 (QSTRT), U4.9 (EP), U5.2 (VSS)
GPIO8: R1.2, U2.10 (IO8)
I2C_PW: U2.17 (IO19)
INT_RTC: R1_PINH1.1, TP15.TP, U2.8 (IO0), U3.3 (SQW/!INT)
IO/BOOT: BOOT_BUTTON.3, BOOT_BUTTON.4, C6.1, R_BOOT.2, U2.15 (IO9)
IO/CHANGE: C10.1, CHANGE_BUTTON.3, CHANGE_BUTTON.4, R_CHANGE.2, U2.23 (IO15)
MISO: D12.1, J4.P7 (DAT0), R8.1, TP6.TP, U1.2 (DO(IO1)), U2.27 (IO2)
MOSI: D11.1, J1.14, J4.P3 (CMD), R7.1, TP7.TP, U1.5 (DI(IO0)), U2.7 (IO7)
unnamed: D7.1 (CATHODE), R_CAPACITOR.2
unnamed: EPD_C1\.1, J1.4
unnamed: EPD_C8.1, J1.20
unnamed: EPD_C2.1, J1.5
unnamed: EPD_C6.1, J1.18
unnamed: C_DELAY.1, IC1.5 (CT)
unnamed: EPD_C7.1, J1.19
unnamed: EPD_C12.1, J1.24
unnamed: EPD_C10.1, J1.22
unnamed: J2.B5, R2-USB.1
unnamed: C1_BAT1.1, D2.1 (CATHODE), IC4.1 (VIN), IC4.3 (CE), Q1.2 (S)
unnamed: R2_BAT.2, U5.5 (PROG)
unnamed: R1_BAT.1, U5.1 (STAT)
unnamed: J2.A5, R2-USB1.2
unnamed: CHG_LED.C, R1_BAT.2
PREVGH: D5.1 (K), EPD_C9.1, J1.21
PREVGL: D4.2 (A), EPD_C11.1, J1.23
RESE: J1.3, Q3.2 (S), R3.1
RESE': R2.2, R3.2, SJ1.2
RESET: C5.1, IC1.1 (VOUT), RESET_BUTTON.3, RESET_BUTTON.4, R_RESET.2, U2.3 (EN)
RTC_RST: U2.16 (IO18), U3.4 (!RST)
RX: TP2.TP, U2.24 (RXD0/GPIO17)
SCK: D10.1, J1.13, J4.P5 (CLK), R6.1, TP8.TP, U1.6 (CLK), U2.6 (IO6)
SCL: J3.4, R2-PINH.1, SENSOR2.4 (SCK), U2.20 (IO22), U3.16 (SCL), U4.7 (SCL)
SDA: J3.3, R1_PINH.1, SENSOR2.3 (SDI), U2.19 (IO21), U3.15 (SDA), U4.8 (SDA)
SRC: C4.1, C4.2, D3.2 (A), D4.1 (K), D5.2 (A), L1.1, Q3.3 (D)
SS_SD: D8.1, J4.P2 (CD/DAT3), R10.1, U2.4 (IO4)
TX: TP1.TP, U2.25 (TXD0/GPIO16)
USB_D+: D1.1 (I/O1_1), U2.14 (IO13)
USB_D-: D1.3 (I/O2_1), U2.13 (IO12)
VBAT: C11.1, Q1.3 (D), TP3.TP, U4.2 (CELL), U4.3 (VDD), U5.3 (VBAT)
VBUS: C1_BAT.1, C4_USB.1, C5_USB.1, CHG_LED.A, D1.5 (VBUS), D2.2 (ANODE), PFMF.050.1.2, Q1.1 (G), R1_PWRUSB.2, TP14.TP, U5.4 (VIN)
VRTC: C8.1, C10_SUPERCAP.2, R_CAPACITOR.1, U3.14 (VBAT)
VUSB: J2.A4, J2.A9, J2.B4, J2.B9, PFMF.050.1.1

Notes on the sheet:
RTC Module DS3231SN
SD0805S020S1R0
Test Pads
Qwiic / Stemma QT
SPI ESD Protection Lines
External NOR Flash 64MB
E-Paper Display Header
EPD Power
DMG2305UX-7
Environmental Sensor BME688
Voltage Supervisor + Reset & Boot / IO Button
Battery Charge Level
ESP32 C6
SD Card
USB C connector & ESD protection
LDO Voltage Regulator
Display Type Selector
E-Paper Drive Circuit
Li-Po Battery Charging Controller
OpenBook Schematic
drawn by: Emanuel-Stefan Stiuj

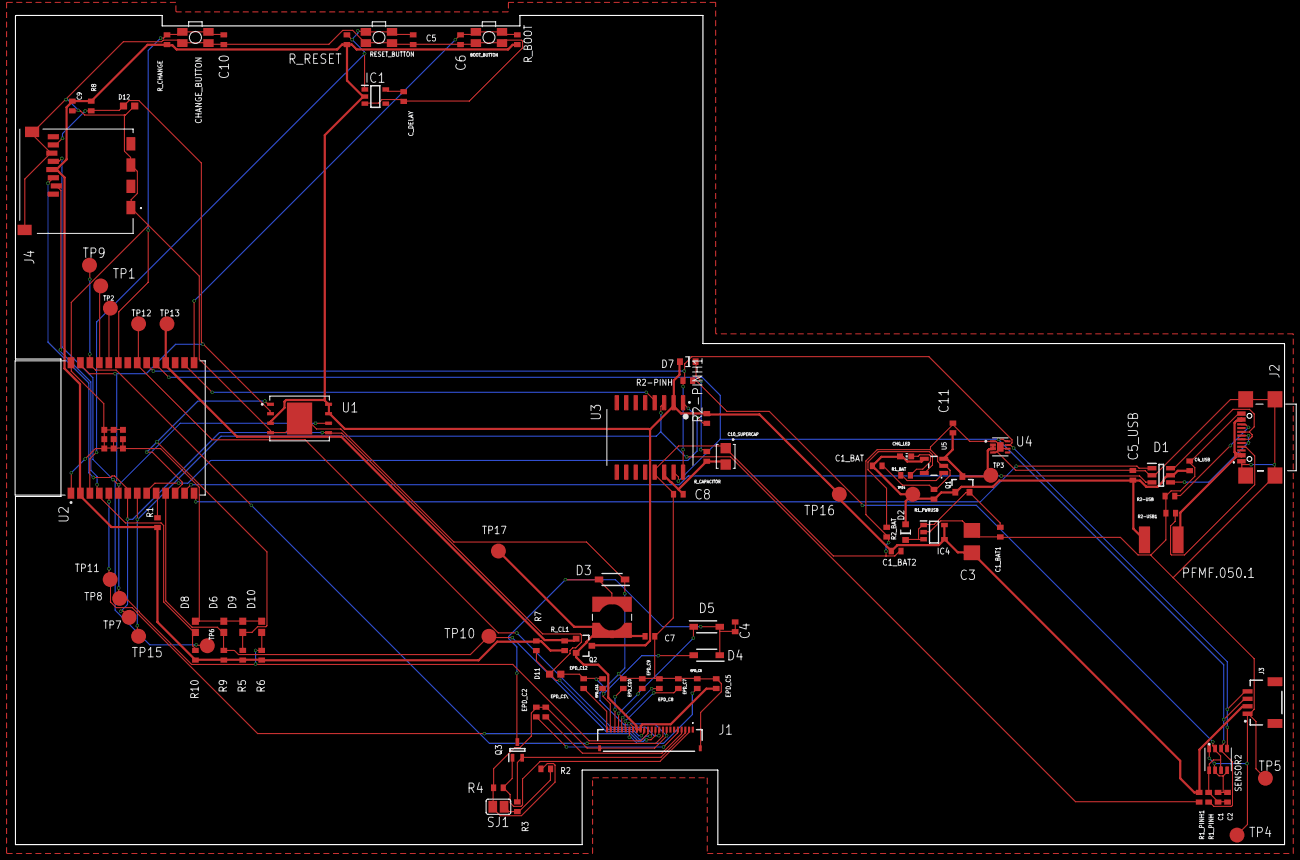
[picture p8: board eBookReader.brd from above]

Board: 2 copper layers, 170.2 x 111.2 mm, 103 parts (0 on the bottom side), 54 nets.

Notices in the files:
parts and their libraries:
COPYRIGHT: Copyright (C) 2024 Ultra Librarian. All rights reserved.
